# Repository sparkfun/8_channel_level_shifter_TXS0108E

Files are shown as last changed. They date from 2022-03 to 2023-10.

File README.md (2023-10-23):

SparkFun Level Shifter - 8 Channel (TXS01018E) 
===========================================

SparkFun Level Shifter - 8 Channel (TXS01018E) (https://www.sparkfun.com/products/19626)

[*SparkFun Level Shifter - 8 Channel (TXS01018E) (BOB-19626)*](https://www.sparkfun.com/products/19626)

The SparkFun Level Shifter - 8 Channel (TXS01018E) features the TXS01018E<sup>&trade;</sup> 8-bit, bi-directional logic level translator from Texas Instruments to shift between devices running at different common microcontroller voltages such as 1.8V, 3.3V and 5V. The TXS0108E can transmit data between ports at max speeds of 110Mbps (push/pull) or 1.2Mbps (open drain).

Repository Contents
-------------------

* **/Documents** - Datasheet
* **/Hardware** - Eagle design files (.brd, .sch)

Documentation
-------------

* **[Hookup Guide](https://learn.sparkfun.com/tutorials/level-shifter---8-channel-txs0108e-hookup-guide)** - A basic Hookup Guide to get started with the SparkFun Level Shifter - 8 Channel (TXS01018E).

Product Versions
----------------

* **[BOB-19626](https://www.sparkfun.com/products/19626)** - Initial Release

Version History
---------------

* v1.0 - Initial Release

License Information
-------------------

This product is _**open source**_! 

Please review the LICENSE.md file for license information. 

If you have any questions or concerns on licensing, please contact technical support on our [SparkFun forums](https://forum.sparkfun.com/viewforum.php?f=152).

Distributed as-is; no warranty is given.

- Your friends at SparkFun.

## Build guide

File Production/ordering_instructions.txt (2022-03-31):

panel size, 184x133mm
PCB thickness, 1.6mm
number of layers, 2
soldermask color, Red
silkscreen color, White
oz copper, 1oz
finish, HASL lead free
stencils, top
pcs per panel, 54
min trace width, 0.2540mm / 0.0100in
min drill size, 0.3048mm / 0.0120in

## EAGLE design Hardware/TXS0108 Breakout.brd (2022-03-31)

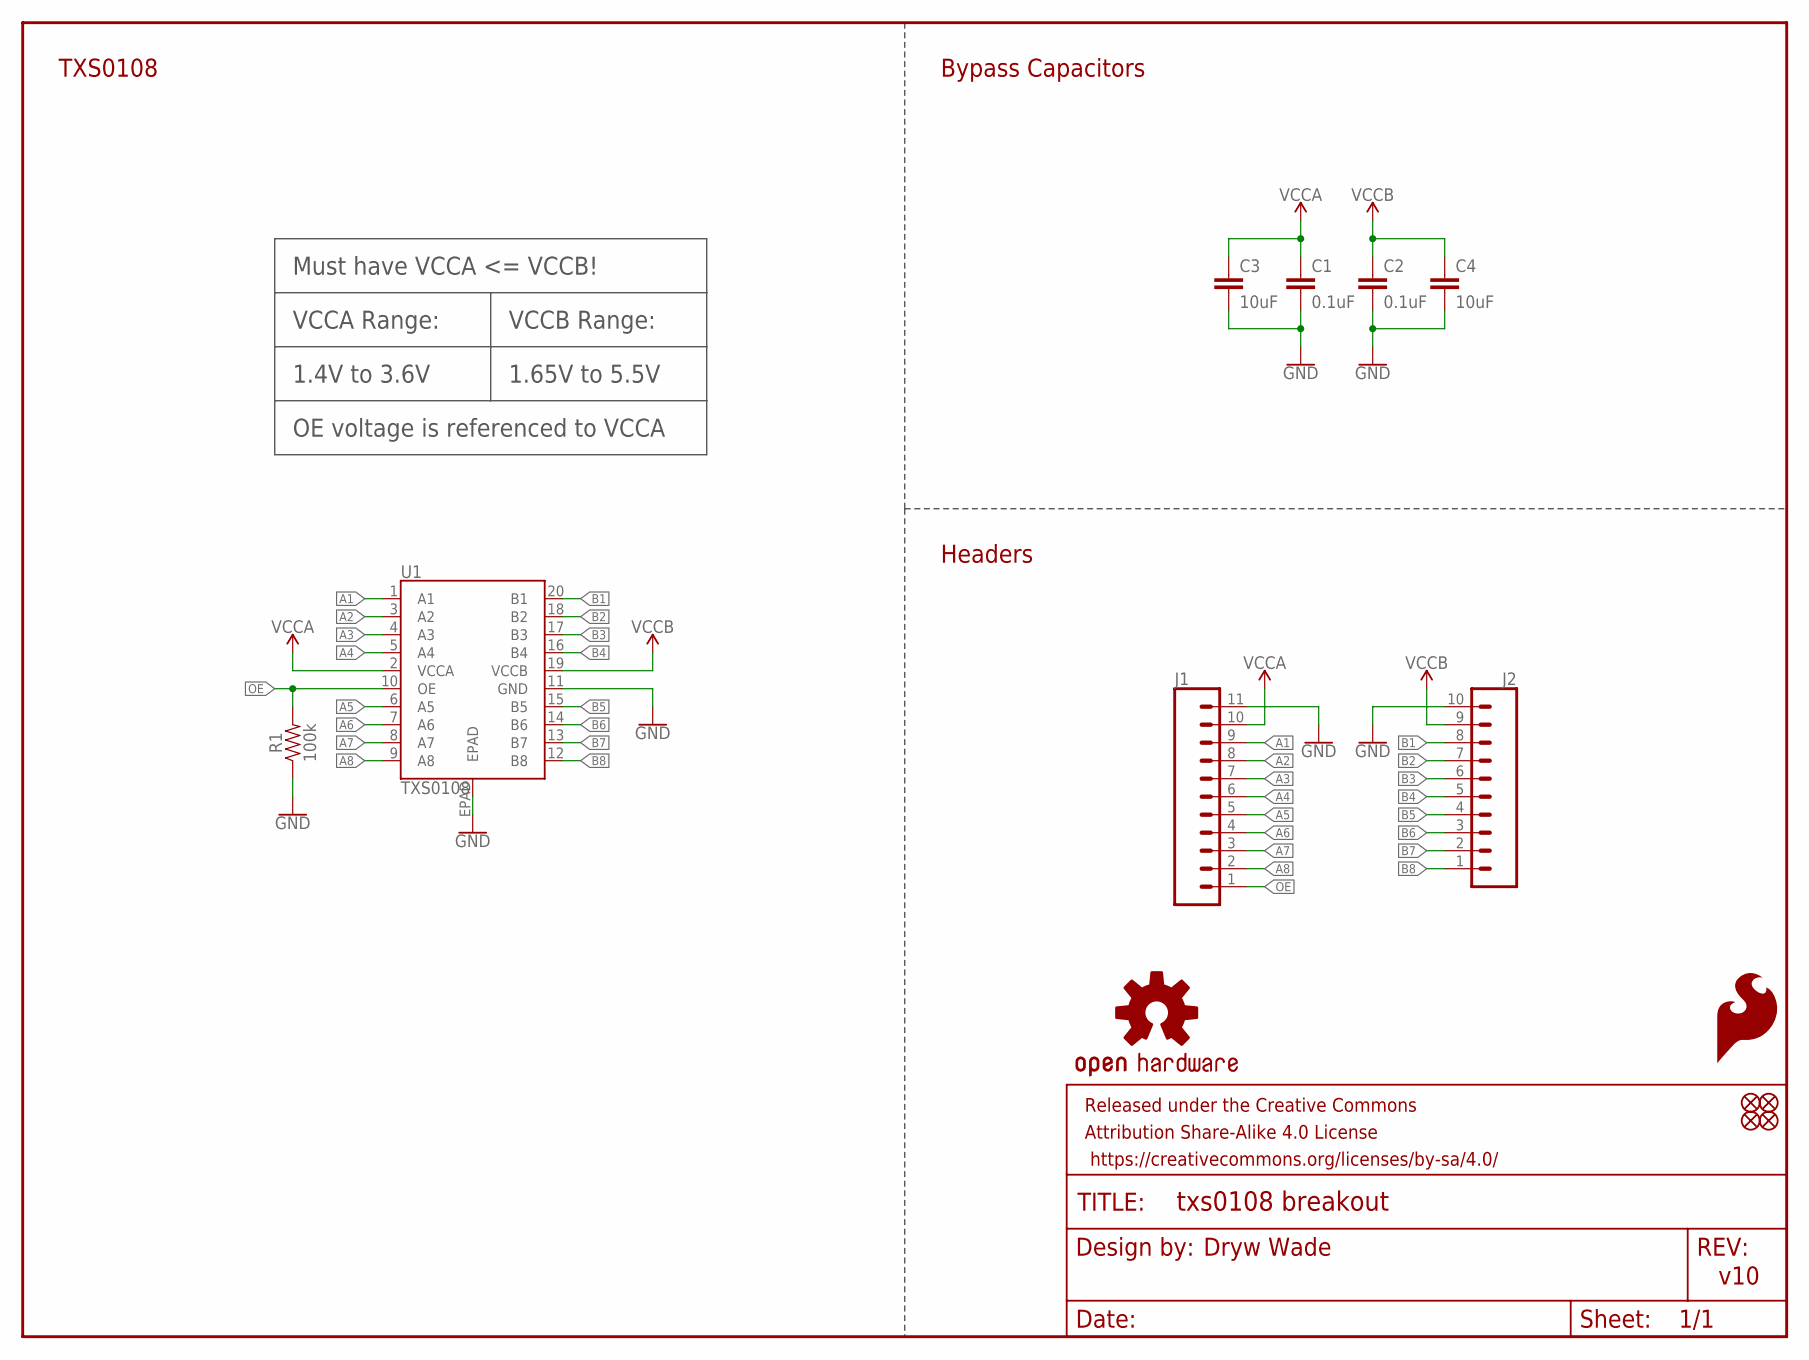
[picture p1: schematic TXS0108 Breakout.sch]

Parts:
C1, C2: 0.1uF; 0603
C3, C4: 10uF; 0603
FD1, FD2, FD3, FD4: FIDUCIAL1X2; FIDUCIAL-1X2
FRAME1: FRAME-LETTER; CREATIVE_COMMONS
J1: CONN_111X11_NO_SILK; 1X11_NO_SILK
J2: CONN_10NO_SILK_PTH_FEMALE; 1X10_NO_SILK
LOGO1: OSHW-LOGOS; OSHW-LOGO-S
LOGO2: SFE_LOGO_FLAME.1_INCH; SFE_LOGO_FLAME_.1
R1: 100k; 0603
U1: TXS0108; VFQFN-20

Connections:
A1: J1.9, U1.1 (A1)
A2: J1.8, U1.3 (A2)
A3: J1.7, U1.4 (A3)
A4: J1.6, U1.5 (A4)
A5: J1.5, U1.6 (A5)
A6: J1.4, U1.7 (A6)
A7: J1.3, U1.8 (A7)
A8: J1.2, U1.9 (A8)
B1: J2.8, U1.20 (B1)
B2: J2.7, U1.18 (B2)
B3: J2.6, U1.17 (B3)
B4: J2.5, U1.16 (B4)
B5: J2.4, U1.15 (B5)
B6: J2.3, U1.14 (B6)
B7: J2.2, U1.13 (B7)
B8: J2.1, U1.12 (B8)
GND: C1.2, C2.2, C3.2, C4.2, J1.11, J2.10, R1.1, U1.11 (GND), U1.EPAD
OE: J1.1, R1.2, U1.10 (OE)
VCCA: C1.1, C3.1, J1.10, U1.2 (VCCA)
VCCB: C2.1, C4.1, J2.9, U1.19 (VCCB)

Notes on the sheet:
Must have VCCA <= VCCB!
VCCA Range:
VCCB Range:
1.4V to 3.6V
1.65V to 5.5V
TXS0108
Headers
Bypass Capacitors
OE voltage is referenced to VCCA
Dryw Wade
v10

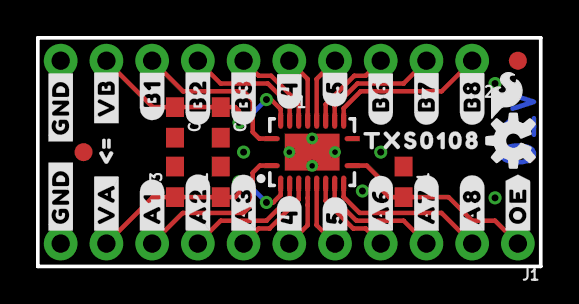
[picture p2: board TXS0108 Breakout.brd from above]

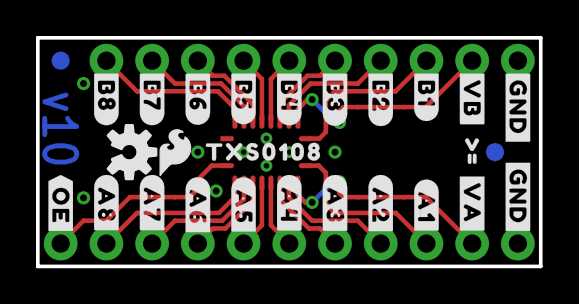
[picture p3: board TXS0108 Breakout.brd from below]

Board: 2 copper layers, 27.9 x 12.7 mm, 65 parts (28 on the bottom side), 20 nets.

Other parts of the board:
LOGO3: SFE_LOGO_FLAME.1_INCH; SFE_LOGO_FLAME_.1
LOGO4: OSHW-LOGOS; OSHW-LOGO-S
U$1, U$2, U$32, U$34: #GND#0
U$3, U$4: #VA#0
U$5: #A1#0
U$6: #A2#0
U$7: #A3#0
U$8: #4#0
U$9: #5#0
U$10: #A6#0
U$11: #A7#0
U$12: #A8#0
U$13: #B8#0
U$14: #B7#0
U$15: #B6#0
U$16: #4#6
U$17: #5#6
U$18: #B3#0
U$19: #B2#0
U$20: #B1#0
U$21: #OE#0
U$22, U$23: #VB#0
U$24: #A1#2
U$25: #A2#2
U$26: #A3#3
U$27: #A4#4
U$28: #A5#5
U$29: #A6#6
U$30: #A7#8
U$31: #A8#9
U$33, U$47: #0
U$35: #B8#9
U$36: #B7#9
U$37: #B6#9
U$38: #B5#9
U$39: #B4#9
U$40: #B3#9
U$41: #B2#9
U$42: #B1#9
U$43, U$44: TXS01080
U$45: #OE#1
U$46, U$48: V0

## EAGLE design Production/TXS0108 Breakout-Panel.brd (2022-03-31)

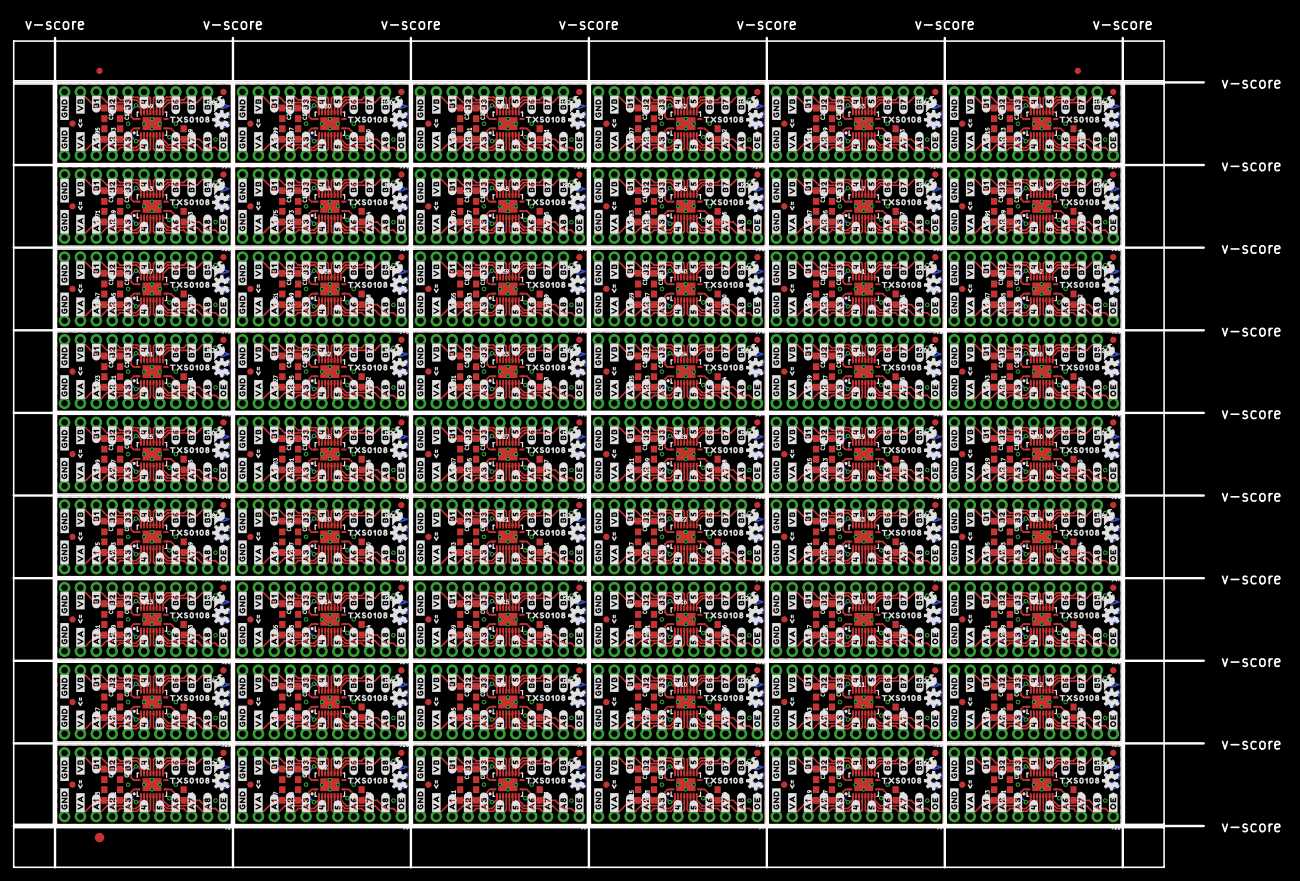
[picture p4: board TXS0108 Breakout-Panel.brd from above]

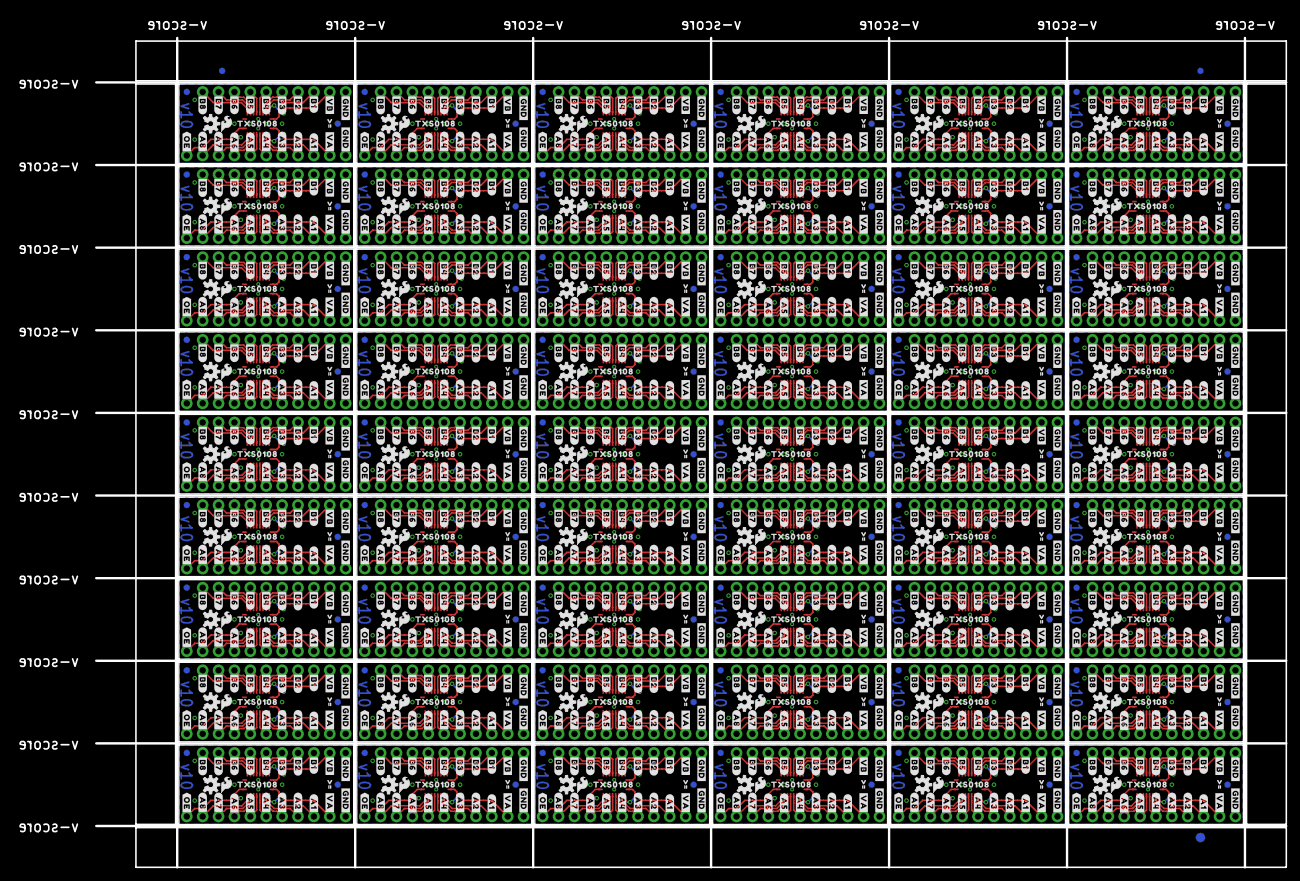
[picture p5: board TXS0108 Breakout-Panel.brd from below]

Board: 2 copper layers, 190.2 x 132.6 mm, 3462 parts (1515 on the bottom side), 1080 nets.

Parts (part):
C1, C2, C5, C6, C9, C10, C13, C14, C17, C18, C21, C22, C25, C26, C29, C30, C33, C34, C37, C38, C41, C42, C45, C46, C49, C50, C53, C54, C57, C58, C61, C62, C65, C66, C69, C70, C73, C74, C77, C78, C81, C82, C85, C86, C89, C90, C93, C94, C97, C98, C101, C102, C105, C106, C109, C110, C113, C114, C117, C118, C121, C122, C125, C126, C129, C130, C133, C134, C137, C138, C141, C142, C145, C146, C149, C150, C153, C154, C157, C158, C161, C162, C165, C166, C169, C170, C173, C174, C177, C178, C181, C182, C185, C186, C189, C190, C193, C194, C197, C198, C201, C202, C205, C206, C209, C210, C213, C214: 0.1uF; 0603
C3, C4, C7, C8, C11, C12, C15, C16, C19, C20, C23, C24, C27, C28, C31, C32, C35, C36, C39, C40, C43, C44, C47, C48, C51, C52, C55, C56, C59, C60, C63, C64, C67, C68, C71, C72, C75, C76, C79, C80, C83, C84, C87, C88, C91, C92, C95, C96, C99, C100, C103, C104, C107, C108, C111, C112, C115, C116, C119, C120, C123, C124, C127, C128, C131, C132, C135, C136, C139, C140, C143, C144, C147, C148, C151, C152, C155, C156, C159, C160, C163, C164, C167, C168, C171, C172, C175, C176, C179, C180, C183, C184, C187, C188, C191, C192, C195, C196, C199, C200, C203, C204, C207, C208, C211, C212, C215, C216: 10uF; 0603
E$1, E$2, E$3, E$4: FIDUCIAL-1X2
E$5, E$6: FIDUCIAL-1.5X3
FD1, FD2, FD3, FD4, FD5, FD6, FD7, FD8, FD9, FD10, FD11, FD12, FD13, FD14, FD15, FD16, FD17, FD18, FD19, FD20, FD21, FD22, FD23, FD24, FD25, FD26, FD27, FD28, FD29, FD30, FD31, FD32, FD33, FD34, FD35, FD36, FD37, FD38, FD39, FD40, FD41, FD42, FD43, FD44, FD45, FD46, FD47, FD48, FD49, FD50, FD51, FD52, FD53, FD54, FD55, FD56, FD57, FD58, FD59, FD60, FD61, FD62, FD63, FD64, FD65, FD66, FD67, FD68, FD69, FD70, FD71, FD72, FD73, FD74, FD75, FD76, FD77, FD78, FD79, FD80, FD81, FD82, FD83, FD84, FD85, FD86, FD87, FD88, FD89, FD90, FD91, FD92, FD93, FD94, FD95, FD96, FD97, FD98, FD99, FD100, FD101, FD102, FD103, FD104, FD105, FD106, FD107, FD108, FD109, FD110, FD111, FD112, FD113, FD114, FD115, FD116, FD117, FD118, FD119, FD120, FD121, FD122, FD123, FD124, FD125, FD126, FD127, FD128, FD129, FD130, FD131, FD132, FD133, FD134, FD135, FD136, FD137, FD138, FD139, FD140, FD141, FD142, FD143, FD144, FD145, FD146, FD147, FD148, FD149, FD150, FD151, FD152, FD153, FD154, FD155, FD156, FD157, FD158, FD159, FD160, FD161, FD162, FD163, FD164, FD165, FD166, FD167, FD168, FD169, FD170, FD171, FD172, FD173, FD174, FD175, FD176, FD177, FD178, FD179, FD180, FD181, FD182, FD183, FD184, FD185, FD186, FD187, FD188, FD189, FD190, FD191, FD192, FD193, FD194, FD195, FD196, FD197, FD198, FD199, FD200, FD201, FD202, FD203, FD204, FD205, FD206, FD207, FD208, FD209, FD210, FD211, FD212, FD213, FD214, FD215, FD216: FIDUCIAL1X2; FIDUCIAL-1X2
J1, J3, J5, J7, J9, J11, J13, J15, J17, J19, J21, J23, J25, J27, J29, J31, J33, J35, J37, J39, J41, J43, J45, J47, J49, J51, J53, J55, J57, J59, J61, J63, J65, J67, J69, J71, J73, J75, J77, J79, J81, J83, J85, J87, J89, J91, J93, J95, J97, J99, J101, J103, J105, J107: 1X11_NO_SILK
J2, J4, J6, J8, J10, J12, J14, J16, J18, J20, J22, J24, J26, J28, J30, J32, J34, J36, J38, J40, J42, J44, J46, J48, J50, J52, J54, J56, J58, J60, J62, J64, J66, J68, J70, J72, J74, J76, J78, J80, J82, J84, J86, J88, J90, J92, J94, J96, J98, J100, J102, J104, J106, J108: 1X10_NO_SILK
LOGO1, LOGO4, LOGO5, LOGO8, LOGO9, LOGO12, LOGO13, LOGO16, LOGO17, LOGO20, LOGO21, LOGO24, LOGO25, LOGO28, LOGO29, LOGO32, LOGO33, LOGO36, LOGO37, LOGO40, LOGO41, LOGO44, LOGO45, LOGO48, LOGO49, LOGO52, LOGO53, LOGO56, LOGO57, LOGO60, LOGO61, LOGO64, LOGO65, LOGO68, LOGO69, LOGO72, LOGO73, LOGO76, LOGO77, LOGO80, LOGO81, LOGO84, LOGO85, LOGO88, LOGO89, LOGO92, LOGO93, LOGO96, LOGO97, LOGO100, LOGO101, LOGO104, LOGO105, LOGO108, LOGO109, LOGO112, LOGO113, LOGO116, LOGO117, LOGO120, LOGO121, LOGO124, LOGO125, LOGO128, LOGO129, LOGO132, LOGO133, LOGO136, LOGO137, LOGO140, LOGO141, LOGO144, LOGO145, LOGO148, LOGO149, LOGO152, LOGO153, LOGO156, LOGO157, LOGO160, LOGO161, LOGO164, LOGO165, LOGO168, LOGO169, LOGO172, LOGO173, LOGO176, LOGO177, LOGO180, LOGO181, LOGO184, LOGO185, LOGO188, LOGO189, LOGO192, LOGO193, LOGO196, LOGO197, LOGO200, LOGO201, LOGO204, LOGO205, LOGO208, LOGO209, LOGO212, LOGO213, LOGO216: OSHW-LOGOS; OSHW-LOGO-S
LOGO2, LOGO3, LOGO6, LOGO7, LOGO10, LOGO11, LOGO14, LOGO15, LOGO18, LOGO19, LOGO22, LOGO23, LOGO26, LOGO27, LOGO30, LOGO31, LOGO34, LOGO35, LOGO38, LOGO39, LOGO42, LOGO43, LOGO46, LOGO47, LOGO50, LOGO51, LOGO54, LOGO55, LOGO58, LOGO59, LOGO62, LOGO63, LOGO66, LOGO67, LOGO70, LOGO71, LOGO74, LOGO75, LOGO78, LOGO79, LOGO82, LOGO83, LOGO86, LOGO87, LOGO90, LOGO91, LOGO94, LOGO95, LOGO98, LOGO99, LOGO102, LOGO103, LOGO106, LOGO107, LOGO110, LOGO111, LOGO114, LOGO115, LOGO118, LOGO119, LOGO122, LOGO123, LOGO126, LOGO127, LOGO130, LOGO131, LOGO134, LOGO135, LOGO138, LOGO139, LOGO142, LOGO143, LOGO146, LOGO147, LOGO150, LOGO151, LOGO154, LOGO155, LOGO158, LOGO159, LOGO162, LOGO163, LOGO166, LOGO167, LOGO170, LOGO171, LOGO174, LOGO175, LOGO178, LOGO179, LOGO182, LOGO183, LOGO186, LOGO187, LOGO190, LOGO191, LOGO194, LOGO195, LOGO198, LOGO199, LOGO202, LOGO203, LOGO206, LOGO207, LOGO210, LOGO211, LOGO214, LOGO215: SFE_LOGO_FLAME.1_INCH; SFE_LOGO_FLAME_.1
R1, R2, R3, R4, R5, R6, R7, R8, R9, R10, R11, R12, R13, R14, R15, R16, R17, R18, R19, R20, R21, R22, R23, R24, R25, R26, R27, R28, R29, R30, R31, R32, R33, R34, R35, R36, R37, R38, R39, R40, R41, R42, R43, R44, R45, R46, R47, R48, R49, R50, R51, R52, R53, R54: 100k; 0603
U1, U2, U3, U4, U5, U6, U7, U8, U9, U10, U11, U12, U13, U14, U15, U16, U17, U18, U19, U20, U21, U22, U23, U24, U25, U26, U27, U28, U29, U30, U31, U32, U33, U34, U35, U36, U37, U38, U39, U40, U41, U42, U43, U44, U45, U46, U47, U48, U49, U50, U51, U52, U53, U54: TXS0108; VFQFN-20
U$1, U$2, U$32, U$34, U$49, U$50, U$56, U$57, U$97, U$98, U$104, U$105, U$145, U$146, U$152, U$153, U$193, U$194, U$200, U$201, U$241, U$242, U$248, U$249, U$289, U$290, U$296, U$297, U$337, U$338, U$344, U$345, U$385, U$386, U$392, U$393, U$433, U$434, U$440, U$441, U$481, U$482, U$488, U$489, U$529, U$530, U$536, U$537, U$577, U$578, U$584, U$585, U$625, U$626, U$632, U$633, U$673, U$674, U$680, U$681, U$721, U$722, U$728, U$729, U$769, U$770, U$776, U$777, U$817, U$818, U$824, U$825, U$865, U$866, U$872, U$873, U$913, U$914, U$920, U$921, U$961, U$962, U$968, U$969, U$1009, U$1010, U$1016, U$1017, U$1057, U$1058, U$1064, U$1065, U$1105, U$1106, U$1112, U$1113, U$1153, U$1154, U$1160, U$1161, U$1201, U$1202, U$1208, U$1209, U$1249, U$1250, U$1256, U$1257, U$1297, U$1298, U$1304, U$1305, U$1345, U$1346, U$1352, U$1353, U$1393, U$1394, U$1400, U$1401, U$1441, U$1442, U$1448, U$1449, U$1489, U$1490, U$1496, U$1497, U$1537, U$1538, U$1544, U$1545, U$1585, U$1586, U$1592, U$1593, U$1633, U$1634, U$1640, U$1641, U$1681, U$1682, U$1688, U$1689, U$1729, U$1730, U$1736, U$1737, U$1777, U$1778, U$1784, U$1785, U$1825, U$1826, U$1832, U$1833, U$1873, U$1874, U$1880, U$1881, U$1921, U$1922, U$1928, U$1929, U$1969, U$1970, U$1976, U$1977, U$2017, U$2018, U$2024, U$2025, U$2065, U$2066, U$2072, U$2073, U$2113, U$2114, U$2120, U$2121, U$2161, U$2162, U$2168, U$2169, U$2209, U$2210, U$2216, U$2217, U$2257, U$2258, U$2264, U$2265, U$2305, U$2306, U$2312, U$2313, U$2353, U$2354, U$2360, U$2361, U$2401, U$2402, U$2408, U$2409, U$2449, U$2450, U$2456, U$2457, U$2497, U$2498, U$2504, U$2505, U$2545, U$2546, U$2552, U$2553: #GND#0
U$3, U$4, U$52, U$53, U$100, U$101, U$148, U$149, U$196, U$197, U$244, U$245, U$292, U$293, U$340, U$341, U$388, U$389, U$436, U$437, U$484, U$485, U$532, U$533, U$580, U$581, U$628, U$629, U$676, U$677, U$724, U$725, U$772, U$773, U$820, U$821, U$868, U$869, U$916, U$917, U$964, U$965, U$1012, U$1013, U$1060, U$1061, U$1108, U$1109, U$1156, U$1157, U$1204, U$1205, U$1252, U$1253, U$1300, U$1301, U$1348, U$1349, U$1396, U$1397, U$1444, U$1445, U$1492, U$1493, U$1540, U$1541, U$1588, U$1589, U$1636, U$1637, U$1684, U$1685, U$1732, U$1733, U$1780, U$1781, U$1828, U$1829, U$1876, U$1877, U$1924, U$1925, U$1972, U$1973, U$2020, U$2021, U$2068, U$2069, U$2116, U$2117, U$2164, U$2165, U$2212, U$2213, U$2260, U$2261, U$2308, U$2309, U$2356, U$2357, U$2404, U$2405, U$2452, U$2453, U$2500, U$2501, U$2548, U$2549: #VA#0
U$5, U$60, U$108, U$156, U$204, U$252, U$300, U$348, U$396, U$444, U$492, U$540, U$588, U$636, U$684, U$732, U$780, U$828, U$876, U$924, U$972, U$1020, U$1068, U$1116, U$1164, U$1212, U$1260, U$1308, U$1356, U$1404, U$1452, U$1500, U$1548, U$1596, U$1644, U$1692, U$1740, U$1788, U$1836, U$1884, U$1932, U$1980, U$2028, U$2076, U$2124, U$2172, U$2220, U$2268, U$2316, U$2364, U$2412, U$2460, U$2508, U$2556: #A1#0
U$6, U$61, U$109, U$157, U$205, U$253, U$301, U$349, U$397, U$445, U$493, U$541, U$589, U$637, U$685, U$733, U$781, U$829, U$877, U$925, U$973, U$1021, U$1069, U$1117, U$1165, U$1213, U$1261, U$1309, U$1357, U$1405, U$1453, U$1501, U$1549, U$1597, U$1645, U$1693, U$1741, U$1789, U$1837, U$1885, U$1933, U$1981, U$2029, U$2077, U$2125, U$2173, U$2221, U$2269, U$2317, U$2365, U$2413, U$2461, U$2509, U$2557: #A2#0
U$7, U$62, U$110, U$158, U$206, U$254, U$302, U$350, U$398, U$446, U$494, U$542, U$590, U$638, U$686, U$734, U$782, U$830, U$878, U$926, U$974, U$1022, U$1070, U$1118, U$1166, U$1214, U$1262, U$1310, U$1358, U$1406, U$1454, U$1502, U$1550, U$1598, U$1646, U$1694, U$1742, U$1790, U$1838, U$1886, U$1934, U$1982, U$2030, U$2078, U$2126, U$2174, U$2222, U$2270, U$2318, U$2366, U$2414, U$2462, U$2510, U$2558: #A3#0
U$8, U$93, U$141, U$189, U$237, U$285, U$333, U$381, U$429, U$477, U$525, U$573, U$621, U$669, U$717, U$765, U$813, U$861, U$909, U$957, U$1005, U$1053, U$1101, U$1149, U$1197, U$1245, U$1293, U$1341, U$1389, U$1437, U$1485, U$1533, U$1581, U$1629, U$1677, U$1725, U$1773, U$1821, U$1869, U$1917, U$1965, U$2013, U$2061, U$2109, U$2157, U$2205, U$2253, U$2301, U$2349, U$2397, U$2445, U$2493, U$2541, U$2589: #4#0
U$9, U$94, U$142, U$190, U$238, U$286, U$334, U$382, U$430, U$478, U$526, U$574, U$622, U$670, U$718, U$766, U$814, U$862, U$910, U$958, U$1006, U$1054, U$1102, U$1150, U$1198, U$1246, U$1294, U$1342, U$1390, U$1438, U$1486, U$1534, U$1582, U$1630, U$1678, U$1726, U$1774, U$1822, U$1870, U$1918, U$1966, U$2014, U$2062, U$2110, U$2158, U$2206, U$2254, U$2302, U$2350, U$2398, U$2446, U$2494, U$2542, U$2590: #5#0
U$10, U$63, U$111, U$159, U$207, U$255, U$303, U$351, U$399, U$447, U$495, U$543, U$591, U$639, U$687, U$735, U$783, U$831, U$879, U$927, U$975, U$1023, U$1071, U$1119, U$1167, U$1215, U$1263, U$1311, U$1359, U$1407, U$1455, U$1503, U$1551, U$1599, U$1647, U$1695, U$1743, U$1791, U$1839, U$1887, U$1935, U$1983, U$2031, U$2079, U$2127, U$2175, U$2223, U$2271, U$2319, U$2367, U$2415, U$2463, U$2511, U$2559: #A6#0
U$11, U$64, U$112, U$160, U$208, U$256, U$304, U$352, U$400, U$448, U$496, U$544, U$592, U$640, U$688, U$736, U$784, U$832, U$880, U$928, U$976, U$1024, U$1072, U$1120, U$1168, U$1216, U$1264, U$1312, U$1360, U$1408, U$1456, U$1504, U$1552, U$1600, U$1648, U$1696, U$1744, U$1792, U$1840, U$1888, U$1936, U$1984, U$2032, U$2080, U$2128, U$2176, U$2224, U$2272, U$2320, U$2368, U$2416, U$2464, U$2512, U$2560: #A7#0
U$12, U$65, U$113, U$161, U$209, U$257, U$305, U$353, U$401, U$449, U$497, U$545, U$593, U$641, U$689, U$737, U$785, U$833, U$881, U$929, U$977, U$1025, U$1073, U$1121, U$1169, U$1217, U$1265, U$1313, U$1361, U$1409, U$1457, U$1505, U$1553, U$1601, U$1649, U$1697, U$1745, U$1793, U$1841, U$1889, U$1937, U$1985, U$2033, U$2081, U$2129, U$2177, U$2225, U$2273, U$2321, U$2369, U$2417, U$2465, U$2513, U$2561: #A8#0
U$13, U$66, U$114, U$162, U$210, U$258, U$306, U$354, U$402, U$450, U$498, U$546, U$594, U$642, U$690, U$738, U$786, U$834, U$882, U$930, U$978, U$1026, U$1074, U$1122, U$1170, U$1218, U$1266, U$1314, U$1362, U$1410, U$1458, U$1506, U$1554, U$1602, U$1650, U$1698, U$1746, U$1794, U$1842, U$1890, U$1938, U$1986, U$2034, U$2082, U$2130, U$2178, U$2226, U$2274, U$2322, U$2370, U$2418, U$2466, U$2514, U$2562: #B8#0
U$14, U$67, U$115, U$163, U$211, U$259, U$307, U$355, U$403, U$451, U$499, U$547, U$595, U$643, U$691, U$739, U$787, U$835, U$883, U$931, U$979, U$1027, U$1075, U$1123, U$1171, U$1219, U$1267, U$1315, U$1363, U$1411, U$1459, U$1507, U$1555, U$1603, U$1651, U$1699, U$1747, U$1795, U$1843, U$1891, U$1939, U$1987, U$2035, U$2083, U$2131, U$2179, U$2227, U$2275, U$2323, U$2371, U$2419, U$2467, U$2515, U$2563: #B7#0
U$15, U$68, U$116, U$164, U$212, U$260, U$308, U$356, U$404, U$452, U$500, U$548, U$596, U$644, U$692, U$740, U$788, U$836, U$884, U$932, U$980, U$1028, U$1076, U$1124, U$1172, U$1220, U$1268, U$1316, U$1364, U$1412, U$1460, U$1508, U$1556, U$1604, U$1652, U$1700, U$1748, U$1796, U$1844, U$1892, U$1940, U$1988, U$2036, U$2084, U$2132, U$2180, U$2228, U$2276, U$2324, U$2372, U$2420, U$2468, U$2516, U$2564: #B6#0
U$16, U$95, U$143, U$191, U$239, U$287, U$335, U$383, U$431, U$479, U$527, U$575, U$623, U$671, U$719, U$767, U$815, U$863, U$911, U$959, U$1007, U$1055, U$1103, U$1151, U$1199, U$1247, U$1295, U$1343, U$1391, U$1439, U$1487, U$1535, U$1583, U$1631, U$1679, U$1727, U$1775, U$1823, U$1871, U$1919, U$1967, U$2015, U$2063, U$2111, U$2159, U$2207, U$2255, U$2303, U$2351, U$2399, U$2447, U$2495, U$2543, U$2591: #4#6
U$17, U$96, U$144, U$192, U$240, U$288, U$336, U$384, U$432, U$480, U$528, U$576, U$624, U$672, U$720, U$768, U$816, U$864, U$912, U$960, U$1008, U$1056, U$1104, U$1152, U$1200, U$1248, U$1296, U$1344, U$1392, U$1440, U$1488, U$1536, U$1584, U$1632, U$1680, U$1728, U$1776, U$1824, U$1872, U$1920, U$1968, U$2016, U$2064, U$2112, U$2160, U$2208, U$2256, U$2304, U$2352, U$2400, U$2448, U$2496, U$2544, U$2592: #5#6
U$18, U$69, U$117, U$165, U$213, U$261, U$309, U$357, U$405, U$453, U$501, U$549, U$597, U$645, U$693, U$741, U$789, U$837, U$885, U$933, U$981, U$1029, U$1077, U$1125, U$1173, U$1221, U$1269, U$1317, U$1365, U$1413, U$1461, U$1509, U$1557, U$1605, U$1653, U$1701, U$1749, U$1797, U$1845, U$1893, U$1941, U$1989, U$2037, U$2085, U$2133, U$2181, U$2229, U$2277, U$2325, U$2373, U$2421, U$2469, U$2517, U$2565: #B3#0
U$19, U$70, U$118, U$166, U$214, U$262, U$310, U$358, U$406, U$454, U$502, U$550, U$598, U$646, U$694, U$742, U$790, U$838, U$886, U$934, U$982, U$1030, U$1078, U$1126, U$1174, U$1222, U$1270, U$1318, U$1366, U$1414, U$1462, U$1510, U$1558, U$1606, U$1654, U$1702, U$1750, U$1798, U$1846, U$1894, U$1942, U$1990, U$2038, U$2086, U$2134, U$2182, U$2230, U$2278, U$2326, U$2374, U$2422, U$2470, U$2518, U$2566: #B2#0
U$20, U$71, U$119, U$167, U$215, U$263, U$311, U$359, U$407, U$455, U$503, U$551, U$599, U$647, U$695, U$743, U$791, U$839, U$887, U$935, U$983, U$1031, U$1079, U$1127, U$1175, U$1223, U$1271, U$1319, U$1367, U$1415, U$1463, U$1511, U$1559, U$1607, U$1655, U$1703, U$1751, U$1799, U$1847, U$1895, U$1943, U$1991, U$2039, U$2087, U$2135, U$2183, U$2231, U$2279, U$2327, U$2375, U$2423, U$2471, U$2519, U$2567: #B1#0
U$21, U$51, U$99, U$147, U$195, U$243, U$291, U$339, U$387, U$435, U$483, U$531, U$579, U$627, U$675, U$723, U$771, U$819, U$867, U$915, U$963, U$1011, U$1059, U$1107, U$1155, U$1203, U$1251, U$1299, U$1347, U$1395, U$1443, U$1491, U$1539, U$1587, U$1635, U$1683, U$1731, U$1779, U$1827, U$1875, U$1923, U$1971, U$2019, U$2067, U$2115, U$2163, U$2211, U$2259, U$2307, U$2355, U$2403, U$2451, U$2499, U$2547: #OE#0
U$22, U$23, U$54, U$55, U$102, U$103, U$150, U$151, U$198, U$199, U$246, U$247, U$294, U$295, U$342, U$343, U$390, U$391, U$438, U$439, U$486, U$487, U$534, U$535, U$582, U$583, U$630, U$631, U$678, U$679, U$726, U$727, U$774, U$775, U$822, U$823, U$870, U$871, U$918, U$919, U$966, U$967, U$1014, U$1015, U$1062, U$1063, U$1110, U$1111, U$1158, U$1159, U$1206, U$1207, U$1254, U$1255, U$1302, U$1303, U$1350, U$1351, U$1398, U$1399, U$1446, U$1447, U$1494, U$1495, U$1542, U$1543, U$1590, U$1591, U$1638, U$1639, U$1686, U$1687, U$1734, U$1735, U$1782, U$1783, U$1830, U$1831, U$1878, U$1879, U$1926, U$1927, U$1974, U$1975, U$2022, U$2023, U$2070, U$2071, U$2118, U$2119, U$2166, U$2167, U$2214, U$2215, U$2262, U$2263, U$2310, U$2311, U$2358, U$2359, U$2406, U$2407, U$2454, U$2455, U$2502, U$2503, U$2550, U$2551: #VB#0
U$24, U$72, U$120, U$168, U$216, U$264, U$312, U$360, U$408, U$456, U$504, U$552, U$600, U$648, U$696, U$744, U$792, U$840, U$888, U$936, U$984, U$1032, U$1080, U$1128, U$1176, U$1224, U$1272, U$1320, U$1368, U$1416, U$1464, U$1512, U$1560, U$1608, U$1656, U$1704, U$1752, U$1800, U$1848, U$1896, U$1944, U$1992, U$2040, U$2088, U$2136, U$2184, U$2232, U$2280, U$2328, U$2376, U$2424, U$2472, U$2520, U$2568: #A1#2
U$25, U$73, U$121, U$169, U$217, U$265, U$313, U$361, U$409, U$457, U$505, U$553, U$601, U$649, U$697, U$745, U$793, U$841, U$889, U$937, U$985, U$1033, U$1081, U$1129, U$1177, U$1225, U$1273, U$1321, U$1369, U$1417, U$1465, U$1513, U$1561, U$1609, U$1657, U$1705, U$1753, U$1801, U$1849, U$1897, U$1945, U$1993, U$2041, U$2089, U$2137, U$2185, U$2233, U$2281, U$2329, U$2377, U$2425, U$2473, U$2521, U$2569: #A2#2
U$26, U$74, U$122, U$170, U$218, U$266, U$314, U$362, U$410, U$458, U$506, U$554, U$602, U$650, U$698, U$746, U$794, U$842, U$890, U$938, U$986, U$1034, U$1082, U$1130, U$1178, U$1226, U$1274, U$1322, U$1370, U$1418, U$1466, U$1514, U$1562, U$1610, U$1658, U$1706, U$1754, U$1802, U$1850, U$1898, U$1946, U$1994, U$2042, U$2090, U$2138, U$2186, U$2234, U$2282, U$2330, U$2378, U$2426, U$2474, U$2522, U$2570: #A3#3
U$27, U$75, U$123, U$171, U$219, U$267, U$315, U$363, U$411, U$459, U$507, U$555, U$603, U$651, U$699, U$747, U$795, U$843, U$891, U$939, U$987, U$1035, U$1083, U$1131, U$1179, U$1227, U$1275, U$1323, U$1371, U$1419, U$1467, U$1515, U$1563, U$1611, U$1659, U$1707, U$1755, U$1803, U$1851, U$1899, U$1947, U$1995, U$2043, U$2091, U$2139, U$2187, U$2235, U$2283, U$2331, U$2379, U$2427, U$2475, U$2523, U$2571: #A4#4
U$28, U$76, U$124, U$172, U$220, U$268, U$316, U$364, U$412, U$460, U$508, U$556, U$604, U$652, U$700, U$748, U$796, U$844, U$892, U$940, U$988, U$1036, U$1084, U$1132, U$1180, U$1228, U$1276, U$1324, U$1372, U$1420, U$1468, U$1516, U$1564, U$1612, U$1660, U$1708, U$1756, U$1804, U$1852, U$1900, U$1948, U$1996, U$2044, U$2092, U$2140, U$2188, U$2236, U$2284, U$2332, U$2380, U$2428, U$2476, U$2524, U$2572: #A5#5
U$29, U$77, U$125, U$173, U$221, U$269, U$317, U$365, U$413, U$461, U$509, U$557, U$605, U$653, U$701, U$749, U$797, U$845, U$893, U$941, U$989, U$1037, U$1085, U$1133, U$1181, U$1229, U$1277, U$1325, U$1373, U$1421, U$1469, U$1517, U$1565, U$1613, U$1661, U$1709, U$1757, U$1805, U$1853, U$1901, U$1949, U$1997, U$2045, U$2093, U$2141, U$2189, U$2237, U$2285, U$2333, U$2381, U$2429, U$2477, U$2525, U$2573: #A6#6
U$30, U$78, U$126, U$174, U$222, U$270, U$318, U$366, U$414, U$462, U$510, U$558, U$606, U$654, U$702, U$750, U$798, U$846, U$894, U$942, U$990, U$1038, U$1086, U$1134, U$1182, U$1230, U$1278, U$1326, U$1374, U$1422, U$1470, U$1518, U$1566, U$1614, U$1662, U$1710, U$1758, U$1806, U$1854, U$1902, U$1950, U$1998, U$2046, U$2094, U$2142, U$2190, U$2238, U$2286, U$2334, U$2382, U$2430, U$2478, U$2526, U$2574: #A7#8
U$31, U$79, U$127, U$175, U$223, U$271, U$319, U$367, U$415, U$463, U$511, U$559, U$607, U$655, U$703, U$751, U$799, U$847, U$895, U$943, U$991, U$1039, U$1087, U$1135, U$1183, U$1231, U$1279, U$1327, U$1375, U$1423, U$1471, U$1519, U$1567, U$1615, U$1663, U$1711, U$1759, U$1807, U$1855, U$1903, U$1951, U$1999, U$2047, U$2095, U$2143, U$2191, U$2239, U$2287, U$2335, U$2383, U$2431, U$2479, U$2527, U$2575: #A8#9
U$33, U$47, U$89, U$91, U$137, U$139, U$185, U$187, U$233, U$235, U$281, U$283, U$329, U$331, U$377, U$379, U$425, U$427, U$473, U$475, U$521, U$523, U$569, U$571, U$617, U$619, U$665, U$667, U$713, U$715, U$761, U$763, U$809, U$811, U$857, U$859, U$905, U$907, U$953, U$955, U$1001, U$1003, U$1049, U$1051, U$1097, U$1099, U$1145, U$1147, U$1193, U$1195, U$1241, U$1243, U$1289, U$1291, U$1337, U$1339, U$1385, U$1387, U$1433, U$1435, U$1481, U$1483, U$1529, U$1531, U$1577, U$1579, U$1625, U$1627, U$1673, U$1675, U$1721, U$1723, U$1769, U$1771, U$1817, U$1819, U$1865, U$1867, U$1913, U$1915, U$1961, U$1963, U$2009, U$2011, U$2057, U$2059, U$2105, U$2107, U$2153, U$2155, U$2201, U$2203, U$2249, U$2251, U$2297, U$2299, U$2345, U$2347, U$2393, U$2395, U$2441, U$2443, U$2489, U$2491, U$2537, U$2539, U$2585, U$2587: #0
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

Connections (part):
A1: J1.9, U1.1
A2: J1.8, U1.3
A3: J1.7, U1.4
A4: J1.6, U1.5
A5: J1.5, U1.6
A6: J1.4, U1.7
A7: J1.3, U1.8
A8: J1.2, U1.9
A9: J3.9, U2.1
A10: J3.8, U2.3
A11: J3.7, U2.4
A12: J3.6, U2.5
A13: J3.5, U2.6
A14: J3.4, U2.7
A15: J3.3, U2.8
A16: J3.2, U2.9
A17: J5.9, U3.1
A18: J5.8, U3.3
A19: J5.7, U3.4
A20: J5.6, U3.5
A21: J5.5, U3.6
A22: J5.4, U3.7
A23: J5.3, U3.8
A24: J5.2, U3.9
A25: J7.9, U4.1
A26: J7.8, U4.3
A27: J7.7, U4.4
A28: J7.6, U4.5
A29: J7.5, U4.6
A30: J7.4, U4.7
A31: J7.3, U4.8
A32: J7.2, U4.9
A33: J9.9, U5.1
A34: J9.8, U5.3
A35: J9.7, U5.4
A36: J9.6, U5.5
A37: J9.5, U5.6
A38: J9.4, U5.7
A39: J9.3, U5.8
A40: J9.2, U5.9
A41: J11.9, U6.1
A42: J11.8, U6.3
A43: J11.7, U6.4
A44: J11.6, U6.5
A45: J11.5, U6.6
A46: J11.4, U6.7
A47: J11.3, U6.8
A48: J11.2, U6.9
A49: J13.9, U7.1
A50: J13.8, U7.3
A51: J13.7, U7.4
A52: J13.6, U7.5
A53: J13.5, U7.6
A54: J13.4, U7.7
A55: J13.3, U7.8
A56: J13.2, U7.9
A57: J15.9, U8.1
A58: J15.8, U8.3
A59: J15.7, U8.4
A60: J15.6, U8.5
A61: J15.5, U8.6
A62: J15.4, U8.7
A63: J15.3, U8.8
A64: J15.2, U8.9
A65: J17.9, U9.1
A66: J17.8, U9.3
A67: J17.7, U9.4
A68: J17.6, U9.5
A69: J17.5, U9.6
A70: J17.4, U9.7
A71: J17.3, U9.8
A72: J17.2, U9.9
A73: J19.9, U10.1
A74: J19.8, U10.3
A75: J19.7, U10.4
A76: J19.6, U10.5
A77: J19.5, U10.6
A78: J19.4, U10.7
A79: J19.3, U10.8
A80: J19.2, U10.9
A81: J21.9, U11.1
A82: J21.8, U11.3
A83: J21.7, U11.4
A84: J21.6, U11.5
A85: J21.5, U11.6
A86: J21.4, U11.7
A87: J21.3, U11.8
A88: J21.2, U11.9
A89: J23.9, U12.1
A90: J23.8, U12.3
A91: J23.7, U12.4
A92: J23.6, U12.5
A93: J23.5, U12.6
A94: J23.4, U12.7
A95: J23.3, U12.8
A96: J23.2, U12.9
A97: J25.9, U13.1
A98: J25.8, U13.3
A99: J25.7, U13.4
A100: J25.6, U13.5
A101: J25.5, U13.6
A102: J25.4, U13.7
A103: J25.3, U13.8
A104: J25.2, U13.9
A105: J27.9, U14.1
A106: J27.8, U14.3
A107: J27.7, U14.4
A108: J27.6, U14.5
A109: J27.5, U14.6
A110: J27.4, U14.7
A111: J27.3, U14.8
A112: J27.2, U14.9
A113: J29.9, U15.1
A114: J29.8, U15.3
A115: J29.7, U15.4
A116: J29.6, U15.5
A117: J29.5, U15.6
A118: J29.4, U15.7
A119: J29.3, U15.8
A120: J29.2, U15.9
A121: J31.9, U16.1
A122: J31.8, U16.3
A123: J31.7, U16.4
A124: J31.6, U16.5
A125: J31.5, U16.6
A126: J31.4, U16.7
A127: J31.3, U16.8
A128: J31.2, U16.9
A129: J33.9, U17.1
A130: J33.8, U17.3
A131: J33.7, U17.4
A132: J33.6, U17.5
A133: J33.5, U17.6
A134: J33.4, U17.7
A135: J33.3, U17.8
A136: J33.2, U17.9
A137: J35.9, U18.1
A138: J35.8, U18.3
A139: J35.7, U18.4
A140: J35.6, U18.5
A141: J35.5, U18.6
A142: J35.4, U18.7
A143: J35.3, U18.8
A144: J35.2, U18.9
A145: J37.9, U19.1
A146: J37.8, U19.3
A147: J37.7, U19.4
A148: J37.6, U19.5
A149: J37.5, U19.6
A150: J37.4, U19.7
A151: J37.3, U19.8
A152: J37.2, U19.9
A153: J39.9, U20.1
A154: J39.8, U20.3
A155: J39.7, U20.4
A156: J39.6, U20.5
A157: J39.5, U20.6
A158: J39.4, U20.7
A159: J39.3, U20.8
A160: J39.2, U20.9
A161: J41.9, U21.1
A162: J41.8, U21.3
A163: J41.7, U21.4
A164: J41.6, U21.5
A165: J41.5, U21.6
A166: J41.4, U21.7
A167: J41.3, U21.8
A168: J41.2, U21.9
A169: J43.9, U22.1
A170: J43.8, U22.3
A171: J43.7, U22.4
A172: J43.6, U22.5
A173: J43.5, U22.6
A174: J43.4, U22.7
A175: J43.3, U22.8
A176: J43.2, U22.9
A177: J45.9, U23.1
A178: J45.8, U23.3
A179: J45.7, U23.4
A180: J45.6, U23.5
A181: J45.5, U23.6
A182: J45.4, U23.7
A183: J45.3, U23.8
A184: J45.2, U23.9
A185: J47.9, U24.1
A186: J47.8, U24.3
A187: J47.7, U24.4
A188: J47.6, U24.5
A189: J47.5, U24.6
A190: J47.4, U24.7
A191: J47.3, U24.8
A192: J47.2, U24.9
A193: J49.9, U25.1
A194: J49.8, U25.3
A195: J49.7, U25.4
A196: J49.6, U25.5
A197: J49.5, U25.6
A198: J49.4, U25.7
A199: J49.3, U25.8
A200: J49.2, U25.9
A201: J51.9, U26.1
A202: J51.8, U26.3
A203: J51.7, U26.4
A204: J51.6, U26.5
A205: J51.5, U26.6
A206: J51.4, U26.7
A207: J51.3, U26.8
A208: J51.2, U26.9
A209: J53.9, U27.1
A210: J53.8, U27.3
A211: J53.7, U27.4
A212: J53.6, U27.5
A213: J53.5, U27.6
A214: J53.4, U27.7
A215: J53.3, U27.8
A216: J53.2, U27.9
A217: J55.9, U28.1
A218: J55.8, U28.3
A219: J55.7, U28.4
A220: J55.6, U28.5
A221: J55.5, U28.6
A222: J55.4, U28.7
A223: J55.3, U28.8
A224: J55.2, U28.9
A225: J57.9, U29.1
A226: J57.8, U29.3
A227: J57.7, U29.4
A228: J57.6, U29.5
A229: J57.5, U29.6
A230: J57.4, U29.7
A231: J57.3, U29.8
A232: J57.2, U29.9
A233: J59.9, U30.1
A234: J59.8, U30.3
A235: J59.7, U30.4
A236: J59.6, U30.5
A237: J59.5, U30.6
A238: J59.4, U30.7
A239: J59.3, U30.8
A240: J59.2, U30.9
A241: J61.9, U31.1
A242: J61.8, U31.3
A243: J61.7, U31.4
A244: J61.6, U31.5
A245: J61.5, U31.6
A246: J61.4, U31.7
A247: J61.3, U31.8
A248: J61.2, U31.9
A249: J63.9, U32.1
A250: J63.8, U32.3
A251: J63.7, U32.4
A252: J63.6, U32.5
A253: J63.5, U32.6
A254: J63.4, U32.7
A255: J63.3, U32.8
A256: J63.2, U32.9
A257: J65.9, U33.1
A258: J65.8, U33.3
A259: J65.7, U33.4
A260: J65.6, U33.5
A261: J65.5, U33.6
A262: J65.4, U33.7
A263: J65.3, U33.8
A264: J65.2, U33.9
A265: J67.9, U34.1
A266: J67.8, U34.3
A267: J67.7, U34.4
A268: J67.6, U34.5
A269: J67.5, U34.6
A270: J67.4, U34.7
A271: J67.3, U34.8
A272: J67.2, U34.9
A273: J69.9, U35.1
A274: J69.8, U35.3
A275: J69.7, U35.4
A276: J69.6, U35.5
A277: J69.5, U35.6
A278: J69.4, U35.7
A279: J69.3, U35.8
A280: J69.2, U35.9
A281: J71.9, U36.1
A282: J71.8, U36.3
A283: J71.7, U36.4
A284: J71.6, U36.5
A285: J71.5, U36.6
A286: J71.4, U36.7
A287: J71.3, U36.8
A288: J71.2, U36.9
A289: J73.9, U37.1
A290: J73.8, U37.3
A291: J73.7, U37.4
A292: J73.6, U37.5
A293: J73.5, U37.6
A294: J73.4, U37.7
A295: J73.3, U37.8
A296: J73.2, U37.9
A297: J75.9, U38.1
A298: J75.8, U38.3
A299: J75.7, U38.4
A300: J75.6, U38.5
A301: J75.5, U38.6
A302: J75.4, U38.7
A303: J75.3, U38.8
A304: J75.2, U38.9
A305: J77.9, U39.1
A306: J77.8, U39.3
A307: J77.7, U39.4
A308: J77.6, U39.5
A309: J77.5, U39.6
A310: J77.4, U39.7
A311: J77.3, U39.8
A312: J77.2, U39.9
A313: J79.9, U40.1
A314: J79.8, U40.3
A315: J79.7, U40.4
A316: J79.6, U40.5
A317: J79.5, U40.6
A318: J79.4, U40.7
A319: J79.3, U40.8
A320: J79.2, U40.9
A321: J81.9, U41.1
A322: J81.8, U41.3
A323: J81.7, U41.4
A324: J81.6, U41.5
A325: J81.5, U41.6
A326: J81.4, U41.7
A327: J81.3, U41.8
A328: J81.2, U41.9
A329: J83.9, U42.1
A330: J83.8, U42.3
A331: J83.7, U42.4
A332: J83.6, U42.5
A333: J83.5, U42.6
A334: J83.4, U42.7
A335: J83.3, U42.8
A336: J83.2, U42.9
A337: J85.9, U43.1
A338: J85.8, U43.3
A339: J85.7, U43.4
A340: J85.6, U43.5
A341: J85.5, U43.6
A342: J85.4, U43.7
A343: J85.3, U43.8
A344: J85.2, U43.9
A345: J87.9, U44.1
A346: J87.8, U44.3
A347: J87.7, U44.4
A348: J87.6, U44.5
A349: J87.5, U44.6
A350: J87.4, U44.7
A351: J87.3, U44.8
A352: J87.2, U44.9
A353: J89.9, U45.1
A354: J89.8, U45.3
A355: J89.7, U45.4
A356: J89.6, U45.5
A357: J89.5, U45.6
A358: J89.4, U45.7
A359: J89.3, U45.8
A360: J89.2, U45.9
A361: J91.9, U46.1
A362: J91.8, U46.3
A363: J91.7, U46.4
A364: J91.6, U46.5
A365: J91.5, U46.6
A366: J91.4, U46.7
A367: J91.3, U46.8
A368: J91.2, U46.9
A369: J93.9, U47.1
A370: J93.8, U47.3
A371: J93.7, U47.4
A372: J93.6, U47.5
A373: J93.5, U47.6
A374: J93.4, U47.7
A375: J93.3, U47.8
A376: J93.2, U47.9
A377: J95.9, U48.1
A378: J95.8, U48.3
A379: J95.7, U48.4
A380: J95.6, U48.5
A381: J95.5, U48.6
A382: J95.4, U48.7
A383: J95.3, U48.8
A384: J95.2, U48.9
A385: J97.9, U49.1
A386: J97.8, U49.3
A387: J97.7, U49.4
A388: J97.6, U49.5
A389: J97.5, U49.6
A390: J97.4, U49.7
A391: J97.3, U49.8
A392: J97.2, U49.9
A393: J99.9, U50.1
A394: J99.8, U50.3
A395: J99.7, U50.4
A396: J99.6, U50.5
A397: J99.5, U50.6
A398: J99.4, U50.7
A399: J99.3, U50.8
A400: J99.2, U50.9
A401: J101.9, U51.1
A402: J101.8, U51.3
A403: J101.7, U51.4
A404: J101.6, U51.5
A405: J101.5, U51.6
A406: J101.4, U51.7
A407: J101.3, U51.8
A408: J101.2, U51.9
A409: J103.9, U52.1
A410: J103.8, U52.3
A411: J103.7, U52.4
A412: J103.6, U52.5
A413: J103.5, U52.6
A414: J103.4, U52.7
A415: J103.3, U52.8
A416: J103.2, U52.9
A417: J105.9, U53.1
A418: J105.8, U53.3
A419: J105.7, U53.4
A420: J105.6, U53.5
A421: J105.5, U53.6
A422: J105.4, U53.7
A423: J105.3, U53.8
A424: J105.2, U53.9
A425: J107.9, U54.1
A426: J107.8, U54.3
A427: J107.7, U54.4
A428: J107.6, U54.5
A429: J107.5, U54.6
A430: J107.4, U54.7
A431: J107.3, U54.8
A432: J107.2, U54.9
B1: J2.8, U1.20
B2: J2.7, U1.18
B3: J2.6, U1.17
B4: J2.5, U1.16
B5: J2.4, U1.15
B6: J2.3, U1.14
B7: J2.2, U1.13
B8: J2.1, U1.12
B9: J4.8, U2.20
B10: J4.7, U2.18
B11: J4.6, U2.17
B12: J4.5, U2.16
B13: J4.4, U2.15
B14: J4.3, U2.14
B15: J4.2, U2.13
B16: J4.1, U2.12
B17: J6.8, U3.20
B18: J6.7, U3.18
B19: J6.6, U3.17
B20: J6.5, U3.16
B21: J6.4, U3.15
B22: J6.3, U3.14
B23: J6.2, U3.13
B24: J6.1, U3.12
B25: J8.8, U4.20
B26: J8.7, U4.18
B27: J8.6, U4.17
B28: J8.5, U4.16
B29: J8.4, U4.15
B30: J8.3, U4.14
B31: J8.2, U4.13
B32: J8.1, U4.12
B33: J10.8, U5.20
B34: J10.7, U5.18
B35: J10.6, U5.17
B36: J10.5, U5.16
B37: J10.4, U5.15
B38: J10.3, U5.14
B39: J10.2, U5.13
B40: J10.1, U5.12
B41: J12.8, U6.20
B42: J12.7, U6.18
B43: J12.6, U6.17
B44: J12.5, U6.16
B45: J12.4, U6.15
B46: J12.3, U6.14
B47: J12.2, U6.13
B48: J12.1, U6.12
B49: J14.8, U7.20
B50: J14.7, U7.18
B51: J14.6, U7.17
B52: J14.5, U7.16
B53: J14.4, U7.15
B54: J14.3, U7.14
B55: J14.2, U7.13
B56: J14.1, U7.12
B57: J16.8, U8.20
B58: J16.7, U8.18
B59: J16.6, U8.17
B60: J16.5, U8.16
B61: J16.4, U8.15
B62: J16.3, U8.14
B63: J16.2, U8.13
B64: J16.1, U8.12
B65: J18.8, U9.20
B66: J18.7, U9.18
B67: J18.6, U9.17
B68: J18.5, U9.16
B69: J18.4, U9.15
B70: J18.3, U9.14
B71: J18.2, U9.13
B72: J18.1, U9.12
B73: J20.8, U10.20
B74: J20.7, U10.18
B75: J20.6, U10.17
B76: J20.5, U10.16
B77: J20.4, U10.15
B78: J20.3, U10.14
B79: J20.2, U10.13
B80: J20.1, U10.12
B81: J22.8, U11.20
B82: J22.7, U11.18
B83: J22.6, U11.17
B84: J22.5, U11.16
B85: J22.4, U11.15
B86: J22.3, U11.14
B87: J22.2, U11.13
B88: J22.1, U11.12
B89: J24.8, U12.20
B90: J24.7, U12.18
B91: J24.6, U12.17
B92: J24.5, U12.16
B93: J24.4, U12.15
B94: J24.3, U12.14
B95: J24.2, U12.13
B96: J24.1, U12.12
B97: J26.8, U13.20
B98: J26.7, U13.18
B99: J26.6, U13.17
B100: J26.5, U13.16
B101: J26.4, U13.15
B102: J26.3, U13.14
B103: J26.2, U13.13
B104: J26.1, U13.12
B105: J28.8, U14.20
B106: J28.7, U14.18
B107: J28.6, U14.17
B108: J28.5, U14.16
B109: J28.4, U14.15
B110: J28.3, U14.14
B111: J28.2, U14.13
B112: J28.1, U14.12
B113: J30.8, U15.20
B114: J30.7, U15.18
B115: J30.6, U15.17
B116: J30.5, U15.16
B117: J30.4, U15.15
B118: J30.3, U15.14
B119: J30.2, U15.13
B120: J30.1, U15.12
B121: J32.8, U16.20
B122: J32.7, U16.18
B123: J32.6, U16.17
B124: J32.5, U16.16
B125: J32.4, U16.15
B126: J32.3, U16.14
B127: J32.2, U16.13
B128: J32.1, U16.12
B129: J34.8, U17.20
B130: J34.7, U17.18
B131: J34.6, U17.17
B132: J34.5, U17.16
B133: J34.4, U17.15
B134: J34.3, U17.14
B135: J34.2, U17.13
B136: J34.1, U17.12
B137: J36.8, U18.20
B138: J36.7, U18.18
B139: J36.6, U18.17
B140: J36.5, U18.16
B141: J36.4, U18.15
B142: J36.3, U18.14
B143: J36.2, U18.13
B144: J36.1, U18.12
B145: J38.8, U19.20
B146: J38.7, U19.18
B147: J38.6, U19.17
B148: J38.5, U19.16
B149: J38.4, U19.15
B150: J38.3, U19.14
B151: J38.2, U19.13
B152: J38.1, U19.12
B153: J40.8, U20.20
B154: J40.7, U20.18
B155: J40.6, U20.17
B156: J40.5, U20.16
B157: J40.4, U20.15
B158: J40.3, U20.14
B159: J40.2, U20.13
B160: J40.1, U20.12
B161: J42.8, U21.20
B162: J42.7, U21.18
B163: J42.6, U21.17
B164: J42.5, U21.16
B165: J42.4, U21.15
B166: J42.3, U21.14
B167: J42.2, U21.13
B168: J42.1, U21.12
B169: J44.8, U22.20
B170: J44.7, U22.18
B171: J44.6, U22.17
B172: J44.5, U22.16
B173: J44.4, U22.15
B174: J44.3, U22.14
B175: J44.2, U22.13
B176: J44.1, U22.12
B177: J46.8, U23.20
B178: J46.7, U23.18
B179: J46.6, U23.17
B180: J46.5, U23.16
B181: J46.4, U23.15
B182: J46.3, U23.14
B183: J46.2, U23.13
B184: J46.1, U23.12
B185: J48.8, U24.20
B186: J48.7, U24.18
B187: J48.6, U24.17
B188: J48.5, U24.16
B189: J48.4, U24.15
B190: J48.3, U24.14
B191: J48.2, U24.13
B192: J48.1, U24.12
B193: J50.8, U25.20
B194: J50.7, U25.18
B195: J50.6, U25.17
B196: J50.5, U25.16
B197: J50.4, U25.15
B198: J50.3, U25.14
B199: J50.2, U25.13
B200: J50.1, U25.12
B201: J52.8, U26.20
B202: J52.7, U26.18
B203: J52.6, U26.17
B204: J52.5, U26.16
B205: J52.4, U26.15
B206: J52.3, U26.14
B207: J52.2, U26.13
B208: J52.1, U26.12
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

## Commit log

2022-03-24 First Board Prototype
    [TXS0108 Breakout.brd, TXS0108 Breakout.sch]
2022-03-28 Design review revision
    [TXS0108 Breakout.brd, TXS0108 Breakout.sch]
2022-03-28 Final Proto Tweaks
    Added GND vias
    Added units to measures
    [TXS0108 Breakout.brd]
2022-03-28 Proto Gerber files
    [TXS0108 Breakout.GBL, TXS0108 Breakout.GBO, TXS0108 Breakout.GBP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]
2022-03-31 Add panelization v10
    [TXS0108 Breakout-Panel.brd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]

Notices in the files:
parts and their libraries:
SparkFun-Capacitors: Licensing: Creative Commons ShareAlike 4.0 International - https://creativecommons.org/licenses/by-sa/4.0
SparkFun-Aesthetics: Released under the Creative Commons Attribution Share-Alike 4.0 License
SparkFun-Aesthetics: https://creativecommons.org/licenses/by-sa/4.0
